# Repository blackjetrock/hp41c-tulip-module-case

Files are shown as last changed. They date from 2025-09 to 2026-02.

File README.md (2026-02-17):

# HP41C TULIP Module Cases

Cases for the HP41C TULIP4041. These are OpenSCAD models for the TULIP cases for the HP41C. The case is a long module case (it pokes out of the end of the calculator about 3cm. It is made in two halves, these clip together using recesses and dimples along the long edges of the case. The OpenSCAD source has several switches at the top of the files that are used to generate each of the two halves of the case. There are also switches to generate the different options of case, such as the recess and bulge for the battery. Other switches can be used to debug the model, for example, the two halves can be displayed together, and a cube can be used to slice the model in order to examine internal dimensions.



## Version 1
This version of the case has a press-fit battery PCB. 


## Version 2
This version has a battery PCB that is soldered to the TULP PCB with stiff wires. There is more space in the top half, to allow for tolerances when sodlering the battery PCB.



## Switches

### top
```
0: No top half is rendered
1: Render top half of case
```


### base
```
0: No lower half is rendered
1: Render lower half of case
```


Setting both top and base to 1 results in a rendring of both halves, in the clipped together positions.



### status_tube
```
1:  Create hole for status LED
```

### bat_pcb_space
```
1:  Create a larger case top, with space for a battery holder and PCB.
```


### add_logo
```
0:  No logo
1:  Put a TULIP logo on the top of the case
```

### lower_external_flush
```
0:  Bottom of lower half of case is flat
1:  Lower half o cae has a step that is flush with the underside of the HP41C when the module
is inserted in the calculator. It provides more support for the module when it is plugged in and on a flat surface.
```


### slice_check

```
0:  Turns on a cube that can be used o chop the model and check interior thicknesses
```

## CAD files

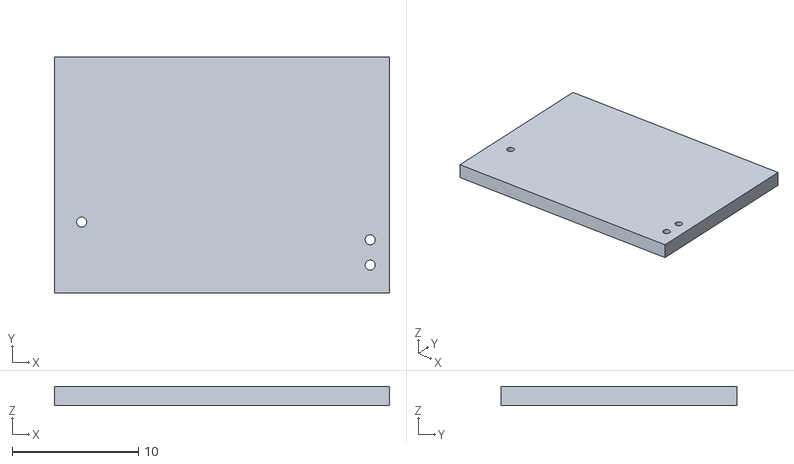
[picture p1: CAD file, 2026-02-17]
module-case/version-2/TULIP_battery_holder.stl
26.5 x 18.7 x 1.51

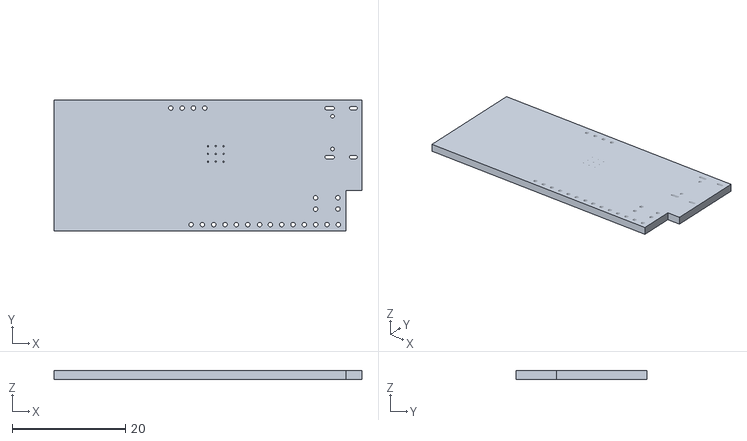
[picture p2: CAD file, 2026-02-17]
module-case/version-2/TUP4041.stl
54.4 x 23.1 x 1.51

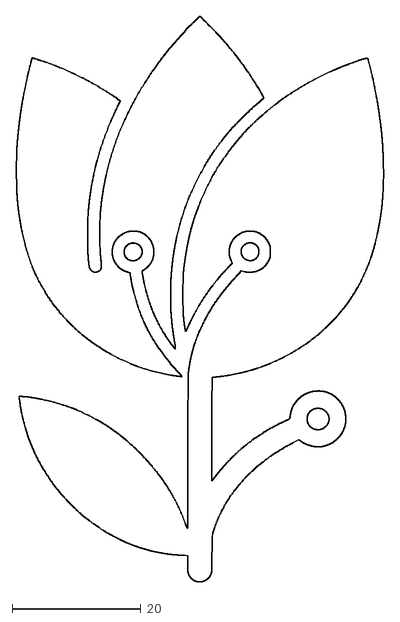
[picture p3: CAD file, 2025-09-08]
module-case/version-2/TULIP_logo.dxf
57.1 x 88.0

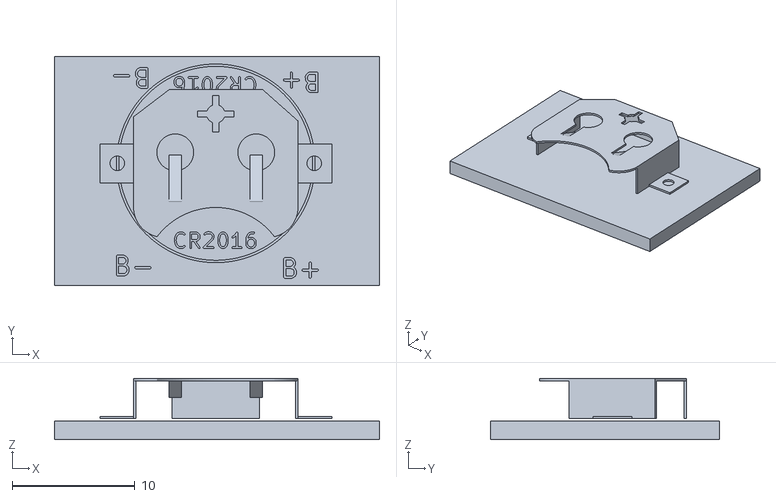
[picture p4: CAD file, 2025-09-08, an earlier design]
module-case/version-1/TULIP_battery_holder.stl
26.5 x 18.7 x 4.98

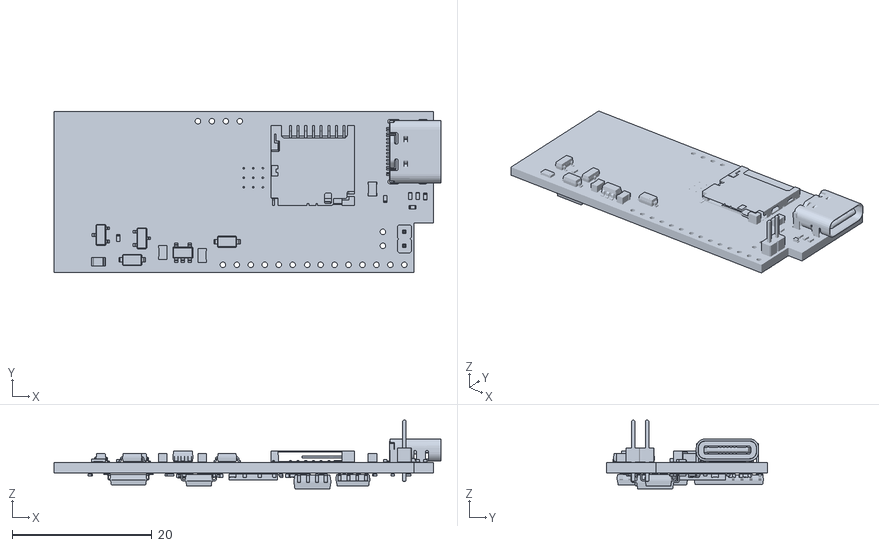
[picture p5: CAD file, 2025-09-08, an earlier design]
module-case/version-1/TUP4041.stl
55.5 x 23.1 x 9.84

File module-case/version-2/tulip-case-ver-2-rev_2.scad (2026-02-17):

////////////////////////////////////////////////////////////////////////
// Case for TULIP4041
//
// Long Module case
//
// All options in this file
//
// 1) Standard case
// 2) Case flush with bottom of calculator
// 3) Higher case outside calculator, for RTC battery
// 4) Added status LED switch, increased PCB size so 0.1mm tolerance. 
//
// Rev7:
//
// 1. PCB rest in top half for connector soldering  done
// 2. Removal of slot in pcb mount                  done
// 3. Connector reference for soldering
// 4. Open up hole for SD card top
//
// Rev9:
// 1. Remove 'hooks' on top of top half USB end PCb supports
// 2. Add a ridge to the HP41C end across the connector pin ridges
// 3. Move the lower half ridge across the HP41C pin ridges 0.5mm towards the HP41C
//
// NOTE: It appears that the cutout PCB cuboid is 1.6mm below (towards the bottom) of the
//       PCB shapes shown with 'show_pcb'. This cutout cuboid is used to cut the top PCB
//       supports. The bottom half PCB supports are cut to height by the pcb()
//       module. This is 1.6mm lower than the cuboid used to cut the top supports. This means
//       that there is a 3.2mm gap between top an bottom supports. This allows the PCB to be
//       in the case at an angle which is needed as the USB end of the PCB has to be in
//       the position it is as the USB connector can go no higher. The front of the PCB
//       is held at the vertical position by ICs resting on the case bottom so can go no
//       lower.
//       Also, as the PCB is at a slight angle, the HP41C connector has to be soldered on
//       with the PCB and connector in th ecase so the conneector is at a slight angle
//       to ensure it is mating with the HP41C along the axis of the HP41C flexi PCB
//       mounting blade.
//
// Rev10
//
// 1.   Front wall shortened to leave a gap at either end so prongs of connector block can fit flush
//      on the inner surface of the top half.
// 2.   Make end of top at connector end flush on the inside.
// 3.   Make recess on side walls of top half larger (move to USB end 0.5mm)
//
//
// Rev 11
//
// 1.   Tilted PCB at 1.8 degrees to match the real PCB in the case.
//      Only the PCB cuboid that is used to cut the PCB support posts off is tilted.
// 2.   Extended the top USB end PCB support posts so they can be cut by the (tilted) pcb model
//
// Rev 12
//
// 1.   A % was left in the file that stopped the ridges on top of the PCB supports from being
//      present in the STL. Removed %
// 2.   The PCB support posts went through the case to the top surface (top half posts) when the
//      nobat option was selected. Put in a conditional to have two different post models for
//      bat and nobat options.
//
///////////////////////////////////////////////////////////////////////////////////////////////////////
//
// Version 2
//
// Version 2 is a change that accomodates the new battery PCB and battery PCB mounting scheme. 
// Instead of clipping the PCB into the top case half, the battery PCB is mounted on three short
// stiff wires soldered onto the TULIP PCB and the battery PCB. The main change is to remove the battery 
// PCB press-fit arrangment in the top half and open up the battery space to allow for more tolerance for
// battery PCB positioning.
//
// V2 Rev1
// Diverges from Version 1 at Version 1 Rev 12
//
//

$fn = 40;

///////////////////////////////////////////////////////////////////////
//
// Options:
//
//
//-----

top                   = 1;
base                  = 0; 
pcb                   = 1;   // STL of Tulip PCB (with components)
bare_pcb              = 1;   // Simple cuboid of PCB size
bat_pcb               = 0;
show_bat_pcb_only     = 0;
bat_extra_y           = 40;
snug_w                = 1;  // Slightly wider
status_tube           = 1;  // Is there a hole for the status LED?
bat_pcb_space         = 1;  // Case larger for battery PCB

add_logo              = 1;
global_cutouts        = 1;
cutout_pcb            = 1;
show_pcb              = 0;
pcb_supports          = 1;
prev_rev_top          = 0;  // Show the previous revision of top half
prev_rev_top_diff     = 0;  // Diff this revision from previous revision
prev_rev_bot          = 0;  // Show the previous revision of bottom half
prev_rev_bot_diff     = 0;  // Diff this revision from previous revision

lower_external_flush  = 0; // Lower case outside the module bay flush
                          // with bottom of calculator

show_pipe             = 0;
show_pipe_type        = 0;
array_pipe            = 0;

sizing_cube           = 0;  // Cube for checking sizes
slice_check           = 0;  // Chop model for interior eamination

// PCB support sizes
top_pcb_support_z     = 8.6;

////////////////////////////////////////////////////////////////////////////////
//
// Test and debug stuff

spike_check =        0;

// IR LED
spike_x =            49.81;
spike_y =            4.84;

// Top edge USB connector
spike_x =            55.81;
spike_y =            22.62;

// Status LED
spike_x =            51.4;
spike_y =            9.425;


// Higher external area, for battery
higher_external_upper = 0;

// Bare PCB position offset to align it with the STL model
bare_pcb_x =         0;
bare_pcb_y =         -0.1;
bare_pcb_z =         -0.45;
  
///////////////////////////////////////////////////////////////////////

top_offset = 0;

ball_r = 0.75;
th = 1.0;

pcb_y = 54.5;
pcb_x = 23.3;

// How far back the PCB is, to allow the contacts to fit in the case
contacts_offset = 13.6;

mod_len = 29.7;

// Mod_len is now a number as changing the pcb length should not change the module length
// Old way to do it:
//    mod_len = pcb_y+contacts_offset+4;;
//
// This revision needs to be shorter by 1mm. PCB size was changed in previous revision

mod_len = 53.375 + 13.6 + 4 - 0;
base_h = 1.2;

// Original base_w: 26.5, this is a bit narrow, 26.9 should givbe a more
// snug fit.abs
base_w = 26.4+(snug_w*0.5);

side_runner_x = 2.4;
side_runner_x_off = 1.5;
side_runner_z = 0.9;

side_wall_x = th;
side_wall_z1 = 2;
side_wall_z2 = 4;
side_wall_y_offset = 12;
side_wall_len = mod_len - side_wall_y_offset;
side_wall_x_offset = -1.5;
side_wall_len = 17.5;

front_wall_z = th;
front_wall_y = th;
front_wall_x = base_w+side_runner_x-1.5/2;

end_wall_y = th;
end_wall_x = base_w;
end_wall_z = 7.4;

psep_x = 0.9;
psep_y = 8.3;
psep_z = th;

long_top_x = base_w + side_runner_x-1.5/2;
long_top_y = mod_len;
long_top_z1 = 5.0;
long_top_z2 = 6.8;
slope_x = 28.0;

// Extra height for battery PCB on top
extra_z = 3;

// Correction applied to V1.0 model
long_correction_z = -1.3;

// Z height of extra bottom thickness for flush with calulator bottom
lower_external_flush_z = 2.0;
lower_external_flush_y = 40.0;

// Extra Z height for higher external upper
higher_external_upper_delta_z = 0.9;

////////////////////////////////////////////////////////////////////////////////

s = 0.3;

module tulip_logo()
{
  translate([-8, 0, 6.5+higher_external_upper_delta_z+(bat_pcb_space*(extra_z-0.64))])
    scale([s, s, 1])
    linear_extrude(height = 0.8, center = true, convexity = 10, twist=0)
    import("TULIP_logo.dxf");
}

////////////////////////////////////////////////////////////////////////////////
// STL PCB model

module tulip_pcb()
{
  rotate([0,0,90])
    {
      translate([-21, -11.5, -3])
        { 
          scale([1,1,1])
            {
              //linear_extrude(height = 1, center = true, convexity = 10,twist=0)
              //              import("TULIP4041_1_6.stl", center=true);
              import("TUP4041.stl", center=true);
            }
          // Cylindrical spike that can be used to check poisitions of 
          // components on the PCB
          
          if(spike_check)
            {
              translate([spike_x, spike_y, 0])
                {
                  cylinder(h=50, d=1, $fn=10, center=true);
                }
            }
        }
    }
}

////////////////////////////////////////////////////////////////////////////////
//
// Import various STLs from the previous revision so that this revision can
// be compared to it

module previous_rev_bot()
{
  rotate([0,0,90])
    {
      translate([-21, -11.5, -2])
        {
          scale([1,1,1])
            {
              //linear_extrude(height = 1, center = true, convexity = 10,twist=0)
              import("../long_tulip_pcb_3/p5t_bat_stat_.stl", center=true);
            }

          // Cylindrical spike that can be used to check poisitions of 
          // components on the PCB
          
          if(spike_check)
            {
              translate([spike_x, spike_y, 0])
                {
                  cylinder(h=50, d=1, $fn=10, center=true);
                }
            }
        }
    }
}

//------------------------------------------------------------------------------
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

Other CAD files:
module-case/version-1/tulip-case-rev_12.scad

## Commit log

2026-02-17 Created diretories for different versions of case. Moved version 1 to directory. This is in anticipation of creating version 2.
    [TULIP_battery_holder.stl, TULIP_logo.dxf, TUP4041.stl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]
2026-02-17 Update README with detailed case description
    Expanded description of the HP41C TULIP module cases, including details about the OpenSCAD models and features.
2026-02-17 Update README with case versions and rendering options
    Added details about case versions and switches for rendering.
2026-02-17 Update README with switch descriptions
    Added descriptions for top and base switches.
2026-02-17 Update README with case feature descriptions and images
    Added images and descriptions for various case features.
2026-02-17 Enhance README with images and version details
    Added images and updated descriptions for case versions.
2026-02-17 Added version 2 case. Modified top to provide more space for soldered battery PCB
    [TULIP_battery_holder.stl, TULIP_logo.dxf, TUP4041.stl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]
2026-02-17 Tidied old files.
    [tulip-case-rev_12.scad]
2026-02-17 Modification to make battery space larger and closer to status LED.
    [tulip-case-ver-2-rev_1.scad]
2026-02-17 Moved V2R2 to properly named file.
    [tulip-case-ver-2-rev_2.scad]
2026-02-17 Renamed file.
    [tulip-case-ver-2-rev_1.scad]
